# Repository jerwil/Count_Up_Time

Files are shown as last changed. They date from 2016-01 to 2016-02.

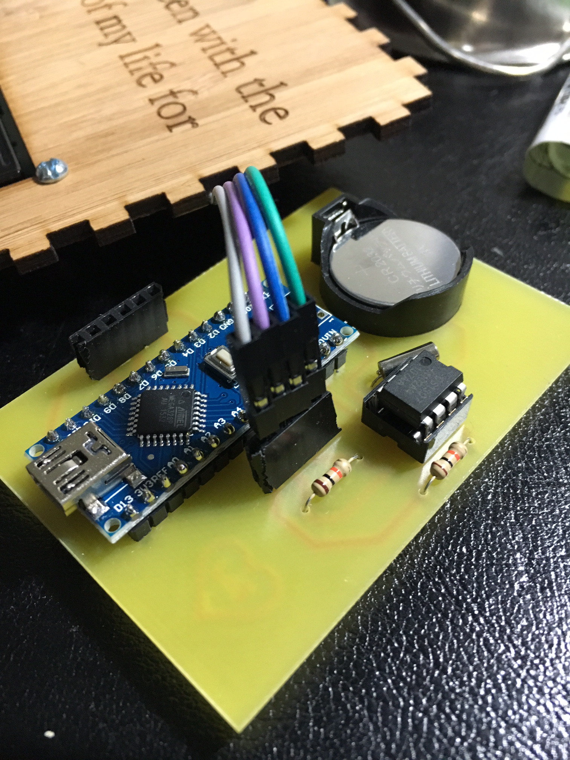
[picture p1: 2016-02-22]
Photos/IMG_2618.JPG

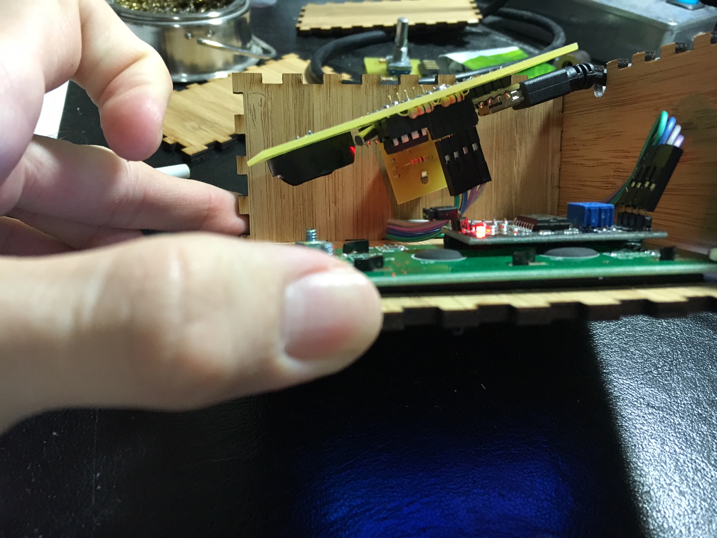
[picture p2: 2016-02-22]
Photos/IMG_2621.JPG

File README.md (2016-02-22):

# Count Up Box

This is a project I created as a Valentine's day gift to my girlfriend. It counts up the amount of time we have been together as a couple in various units.

![] (https://github.com/jerwil/Count_Up_Time/raw/master/Photos/Front.JPG "Front View")
![] (https://github.com/jerwil/Count_Up_Time/raw/master/Photos/Back.JPG "Back View")

## Features

* Displays amount of time since our first date in various units of time.
* Uses a rotary encoder to determine direction knob is turned.
* Backlight can be toggled using rotary encoder's built in momentary button.

## How to Use

* Press the button to turn on/off the backlight.
* Turn the knob to change the units being displayed or the current time and date.
* When displaying current time or date, hold down the button for 3 seconds to edit. Hold down again to switch between hours and minutes.

## Blog Post

Check out the associated blog post here: [Count up Box - A Valentine's Day Gift](http://www.jeremyadamwilson.com/count-up-box/)

## Demo Video

[Demo Video](https://youtu.be/PbRNsSK7r4M)

## Requirements

### Software

I used the LiquidCrystal_I2C library, which you can obtain here: [LiquidCrystal I2C](https://github.com/marcoschwartz/LiquidCrystal_I2C)

### Hardware

* Arduino Nano (or equivalent)
* DS1307 RTC (Real time clock)
* 32.768 kHz crystal oscillator
* 220Ω resistor
* 4 10kΩ resistors (2 for rotary encoder, 2 for RTC)
* 1602 LCD Screen with HD44780 controller
* IIC/I2C Serial Interface Adapter Module (To communicate to screen via I2C)
* Rotary encoder
* Battery holder
* Body/housing (lasercut design included in repository)

![] (https://github.com/jerwil/Count_Up_Time/raw/master/Photos/IMG_2618.JPG "Circuit board picture")
![] (https://github.com/jerwil/Count_Up_Time/raw/master/Photos/IMG_2620.JPG "View inside box")

### Schematics

![] (https://github.com/jerwil/Count_Up_Time/raw/master/Photos/Count%20Up%20Box%20Schematic%20Production_pcb.png "Circuit Board Layout")
![] (https://github.com/jerwil/Count_Up_Time/raw/master/Photos/Rotary%20Encoder%20Mini%20Board_pcb.png "Rotary Encoder Board")

See the included Fritzing diagram (.fzz file) for details.

### License

<br /><span xmlns:dct="http://purl.org/dc/terms/" property="dct:title">Count up box</span> by <a xmlns:cc="http://creativecommons.org/ns#" href="http://www.JeremyAdamWilson.com">Jeremy Wilson</a> is licensed under a <a rel="license" href="http://creativecommons.org/licenses/by-nc/4.0/">Creative Commons Attribution-NonCommercial 4.0 International License</a>.

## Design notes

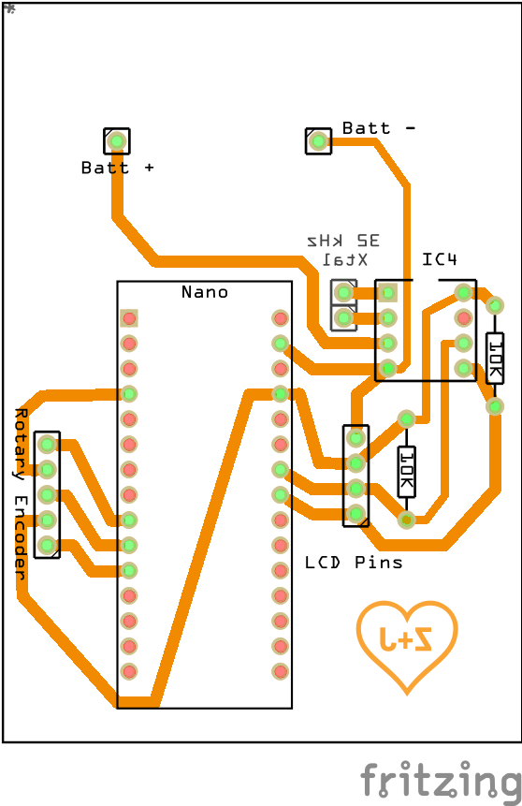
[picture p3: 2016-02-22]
Photos/Count Up Box Schematic Production_pcb.png

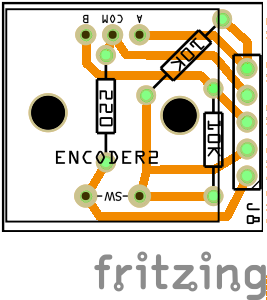
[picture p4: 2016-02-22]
Photos/Rotary Encoder Mini Board_pcb.png

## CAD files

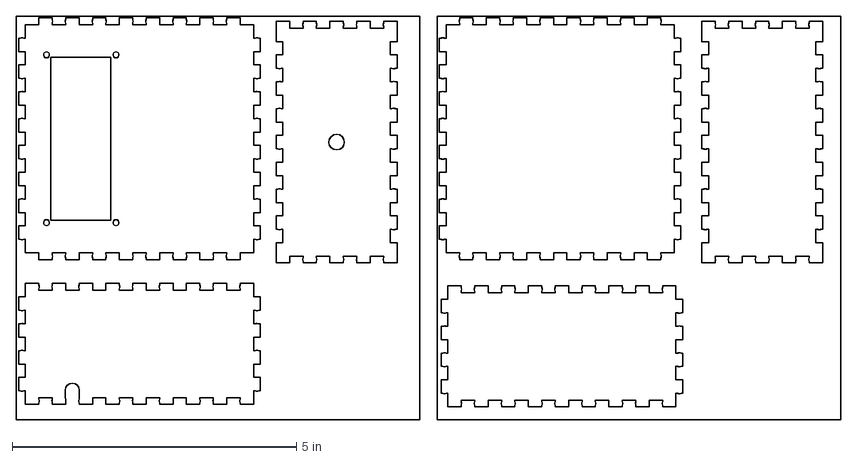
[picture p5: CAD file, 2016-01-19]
Laser Cutting Files/Time count up box 2 sheets.dxf
14.5 x 7.10 in

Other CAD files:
Laser Cutting Files/Time count up box 2 sheets.dwg

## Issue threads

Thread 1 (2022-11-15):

lcd blinking

Joscorb, 2022-11-15:
hello, when I tried this and uploaded the code, the lcd started blinking and changing display fastly and by it self. please any help?

jerwil, 2022-11-18:
Hi, I think it's cool that you're trying out my project! If you're having issues with the LCD, I would suggest that you isolate the problem by trying the example code from the LiquidCrystal_I2C library. If you find the same behavior using the example code, then I would suggest you check your wiring and power to make sure the physical setup is correct.

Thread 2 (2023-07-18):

"Set time" and "Set date" not working

BlindForLove, 2023-07-18:
Hi, it's been a while since the first version (7 years ago)

I hope you could help me with this problem.

When I upload the code everything works fine except 3 things:

1: the seconds counter does not update even in the rtc is working
2: if I move the rotatory encoder to the "The date" mode, after 2 seconds of not touching anything, the code goes automatically to "set date".
3: The same as 2 but with the time

Edit: I would be very pleased if I could get anyway to contact directly to you. tysm
Edit 2: It seems that problem 2 and 3 are caused by the rotary encoder switch, it seems like when it is not pressed, it acts like it is pressed and viceversa,  any solution to this?
Edit 3:Solved! If anyone has the same problem just change this line:

  **if (button_state == HIGH){**
   button_hi = true;
   timeout = 0;
  }
  else {button_hi = false;}

to this one:

  **if (button_state == LOW){**
   button_hi = true;
   timeout = 0;
  }
  else {button_hi = false;}

jerwil, 2023-07-19:
Thanks for taking the time to write up a solution when you figured this out! It could perhaps be the case that you are using a rotary encoder with a normally-closed button rather than a normally-open one. I would love to see the finished product when you're done!

Closed 2023-07-18.

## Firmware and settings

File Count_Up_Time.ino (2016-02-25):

// Date and time functions using a DS1307 RTC connected via I2C and Wire lib

// http://www.geeetech.com/wiki/index.php/Serial_I2C_1602_16%C3%972_Character_LCD_Module

// https://learn.adafruit.com/i2c-spi-lcd-backpack/connect-to-i2c

// https://github.com/marcoschwartz/LiquidCrystal_I2C The library used

// http://arduino.cc/playground/Main/I2cScanner


#include <RTClib.h>

/*
  Blink
  Turns on an LED on for one second, then off for one second, repeatedly.
 
  This example code is in the public domain.
 */

#include <Wire.h>
#include <LiquidCrystal_I2C.h>



LiquidCrystal_I2C lcd(0x27,16,2);  // set the LCD address to 0x27 for a 16 chars and 2 line display

RTC_DS1307 RTC;
 
// Hardware variables
const int pin_A = 6;  // pin 12
const int pin_B = 7;  // pin 11
const int ButtonPin = 8;

int MonthDayCounts[12] = {31,28,31,30,31,30,31,31,30,31,30,31}; // The number of days in each month


// Variables for the rotary encodier
unsigned char encoder_A;
unsigned char encoder_B;
unsigned char encoder_A_prev=0;
int clockwise = 0;
int counterclockwise = 0;

double mode = 0;
char* sub_mode = "hour set";

// Variables to keep track of last string printed to ensure screen is only changed when input changes
String LastString1;
String LastString2;


// Button press completion check variables
int button_state = 0;
int button_pushed = 0; // This is the indicator that the button was pushed and released
int button_counter = 0; // This is used to detect how long the button is held for
int button_press_initiate[1];     // storage for button press function
int button_press_completed[1];    // storage for button press function
int timeout = 0; // Time out for not pushing the button for a while
boolean button_hi = false;

// Boolean for the backlight LED status
bool LCDon = true;

//Boolean for cursor status
bool cursoron = false;

// Variables for displaying time
int hour_int = 0;
int minute_int = 0;
int second_int = 0;
int month_int = 0;
int day_int = 0;
int year_int = 0;
int digit_array[8] = {0,0,0,0,0,0,0,0};
int time_array[3] = {0,0,0};

// Tick timer veriables
double second_timer[1] = {0}; // This is used to keep track of the timer used to tick for each second
int old_second = 0; //This is used for the tick mechanism
int now_second = 0;
unsigned long currentTime;
int cursor_blink = 0;

// the setup routine runs once when you press reset:
void setup() {
  Serial.begin(57600); 
#ifdef AVR
  Wire.begin();
#else
  Wire1.begin(); // Shield I2C pins connect to alt I2C bus on Arduino Due
#endif
  RTC.begin();

    if (! RTC.isrunning()) {
    Serial.println("RTC is NOT running!");
    // following line sets the RTC to the date & time this sketch was compiled
    //RTC.adjust(DateTime(F(__DATE__), F(__TIME__)));
    // This line sets the RTC with an explicit date & time, for example to set
    // January 21, 2014 at 3am you would call:
    //RTC.adjust(DateTime(2014, 1, 21, 3, 0, 0));
  }

//RTC.adjust(DateTime(F(__DATE__), F(__TIME__)));
               
  pinMode(pin_A, INPUT);
  pinMode(pin_B, INPUT);
  pinMode(ButtonPin, INPUT);

  lcd.init();
  lcd.backlight();    
}


// the loop routine runs over and over again forever:
void loop() {
  clockwise = 0;
  encoder_A = digitalRead(pin_A);    // Read encoder pins
  encoder_B = digitalRead(pin_B);   
  if((!encoder_A) && (encoder_A_prev)){
    // A has gone from high to low 
    if(encoder_B) {
      Serial.println("Clockwise");
      if (mode != 5.5 && mode != 6.5){mode += 1;}
      // B is high so clockwise
      clockwise = 1;
      timeout = 0;            
    }   
    else {
      Serial.println("Counter Clockwise");
      if (mode != 5.5 && mode != 6.5){mode -= 1;} 
      // B is low so counter-clockwise      
      clockwise = -1;
      timeout = 0;              
    }   
  }
  encoder_A_prev = encoder_A;
  
  button_state = digitalRead(ButtonPin);
  button_pushed = button_press (button_state, button_press_initiate, button_press_completed);


  if (button_state == HIGH){
   button_hi = true;
   timeout = 0; 
  }
  else {button_hi = false;}


// Toggle the backlight with a button press
  if (button_pushed == 1){
    if (LCDon){LCDon = false;}
    else {LCDon = true;}
  }


  if (mode < 0){mode = 6;}
  else if (mode >= 7){mode = 0;}

DateTime now = RTC.now();
DateTime aniv = (1422126000); // The unixtime format of our anniversary date

  month_int = now.month();
  day_int = now.day();
  year_int = now.year();
  hour_int = now.hour();
  minute_int = now.minute();
  second_int = now.second();


  if (now.year() % 4 == 0){MonthDayCounts[1] = 29;}
  else {MonthDayCounts[1] = 28;}

  long SecondsSince = now.unixtime() - aniv.unixtime();
  long MinutesSince = SecondsSince/60;
  long HoursSince = MinutesSince/60;
  long DaysSince = HoursSince/24;
  long DaysOfMonthSince = MonthDayCounts[now.month()-2]- aniv.day() + now.day();
  long MonthsSince = (now.year()-aniv.year())*12+(now.month()-aniv.month()-1);
  if (now.day() >= aniv.day()){
  MonthsSince += 1;
  DaysOfMonthSince = now.day()- aniv.day();
  }
  
    
    
  if (mode == 0){
      printstring1(String(SecondsSince));
      printstring2("Seconds");
  }
  else if (mode == 1){
      printstring1(String(MinutesSince));
      printstring2("Minutes");
  }
  else if (mode == 2){
      printstring1(String(HoursSince));
      printstring2("Hours");
  }
  else if (mode == 3){
      printstring1(String(DaysSince));
      printstring2("Days");
  }
  else if (mode == 4){
      printstring1(String(MonthsSince) + " Months");
      printstring2(String(DaysOfMonthSince) + " Days");
  }
  else if (mode == 5){
    if (tick(1000, second_timer) == 1){  
      if (button_hi == true){ 
        if (button_counter >= 2) { // This code checks to see if the button has been held down long enough to set time
        mode = 5.5;
        button_counter = 0;
        button_pushed = 0;
        timeout = 0;
        sub_mode = "hour set"; 
        }
      button_counter += 1;
      }
      else {
         button_counter = 0; 
      }
    }
 
    time_to_array(hour_int, minute_int, second_int);
    String stringOne =  String(digit_array[0]) + String(digit_array[1]) + ':' + String(digit_array[2]) + String(digit_array[3]) + ':' + String(digit_array[4] + String(digit_array[5]));
    printstring1(stringOne);
    printstring2("The time");
  }
  else if (mode == 5.5){ 
    if (tick(1000, second_timer) == 1){  
      if (button_hi == true){ 
      button_counter += 1;
      }
      else {
         button_counter = 0; 
         timeout += 1;
      }
      if (cursor_blink == 0){
        cursor_blink = 1;
        lcd.cursor();
      }
      else if (cursor_blink == 1){
        cursor_blink = 0;
        lcd.noCursor();
      }
      }
    if (timeout >= 60){
      mode = 5;
      timeout = 0;
      lcd.noCursor();
    }
    if (sub_mode == "hour set"){
    lcd.setCursor(1,0);
    if (clockwise == 1 && time_array[0] < 24){
      time_array[0] += 1;
      }
    else if (clockwise == -1 && time_array[0] > 0){
      time_array[0] -= 1;
    }
    if (button_counter >= 2) { // This code checks to see if the button has been held down long enough to change to setting minutes
      sub_mode = "minute set";
      button_counter = 0;
      button_pushed = 0;
      timeout = 0;
      button_press_initiate[0] = 0; 
    }    
    }
    else if (sub_mode == "minute set"){
    lcd.setCursor(4,0);
    if (clockwise == 1 && time_array[1] < 59){
      time_array[1] += 1;
      }
    else if (clockwise == -1 && time_array[1] > 0){
      time_array[1] -= 1;
    }
    if (button_counter >= 2) {
      mode = 5;
      sub_mode = "hour set";
      button_counter = 0;
      button_pushed = 0;
      timeout = 0;
      button_press_initiate[0] = 0;
      lcd.noCursor();
      RTC.adjust(DateTime(now.year(), now.month(), now.day(), time_array[0], time_array[1], now.second())); 
    }    
    }
    else{
    mode = 5;
    sub_mode = "hour set";
    }
 
    time_to_array(time_array[0], time_array[1], time_array[2]);
    
    String stringOne =  String(digit_array[0]) + String(digit_array[1]) + ':' + String(digit_array[2]) + String(digit_array[3]) + ':' + String(digit_array[4] + String(digit_array[5]));
    printstring1(stringOne);
    printstring2("Time Set");
    LCDon = true;
  }
  else if (mode == 6){
    if (tick(1000, second_timer) == 1){  
      if (button_hi == true){ // This code checks to see if the button has been held down long enough to set date
        if (button_counter >= 3) {
        mode = 6.5;
        button_counter = 0;
        button_pushed = 0;
        timeout = 0;
        sub_mode = "month set";
        date_to_array(now.month(), now.day(), now.year()); 
        }
      button_counter += 1;
      }
      else {
         button_counter = 0; 
      }
    }
    String stringOne =  String(month_int) + '/' + String(day_int) + '/' + String(year_int);
    printstring1(stringOne);
    printstring2("The Date");
  }
  else if (mode == 6.5){
    if (tick(1000, second_timer) == 1){  
      if (button_hi == true){ // This code checks to see if the button has been held down long enough to set date
        if (button_counter >= 3) {
        mode = 6;
        button_counter = 0;
        button_pushed = 0;
        timeout = 0;
        button_press_initiate[0] = 0; 
        }
      button_counter += 1;
      }
      else {
         button_counter = 0; 
         timeout += 1;
      }
      if (cursor_blink == 0){
        cursor_blink = 1;
        lcd.cursor();
      }
      else if (cursor_blink == 1){
        cursor_blink = 0;
        lcd.noCursor();
      }      
    }
    if (timeout >= 60){
      mode = 6;
      timeout = 0;
    }
    if (sub_mode == "month set"){
    lcd.setCursor(1,0);
    if (clockwise == 1 && time_array[0] < 12){
      time_array[0] += 1;
      }
    else if (clockwise == -1 && time_array[0] > 1){
      time_array[0] -= 1;
    }
    if (button_counter >= 2) {
      sub_mode = "day set";
      button_counter = 0;
      button_pushed = 0;
      timeout = 0;
      button_press_initiate[0] = 0; 
    }    
    }
    else if (sub_mode == "day set"){
      lcd.setCursor(4,0);
      if (clockwise == 1 && time_array[1] < MonthDayCounts[time_array[0]-1]){ // Don't allow a day not within current month. This is why month is set first!
        time_array[1] += 1;
        }
      else if (clockwise == -1 && time_array[1] > 1){
        time_array[1] -= 1;
      }
      if (button_counter >= 2) {
        sub_mode = "year set";
        button_counter = 0;
        button_pushed = 0;
        timeout = 0;
        button_press_initiate[0] = 0; 
      }    
    }
    else if (sub_mode == "year set"){
    lcd.setCursor(9,0);
    if (clockwise == 1){
      time_array[2] += 1;
      }
    else if (clockwise == -1 && time_array[2] > 1971){
      time_array[2] -= 1;
    }
    if (button_counter >= 2) {
      mode = 6;
      sub_mode = "hour set";
      button_counter = 0;
      button_pushed = 0;
      timeout = 0;
      button_press_initiate[0] = 0;
      lcd.noCursor();
      RTC.adjust(DateTime(time_array[2], time_array[0], time_array[1], now.hour(), now.minute(), now.second())); 
    }    
    }
    date_to_array(time_array[0], time_array[1], time_array[2]);
    printstring1(String(digit_array[0]) + String(digit_array[1]) + '/' + String(digit_array[2]) + String(digit_array[3]) + '/' + String(time_array[2]));
    printstring2("Set Date");
    LCDon = true;
  }  
  else {
    printstring1("Error!");
    printstring2("");
  } 

if (LCDon){lcd.backlight();}
else {lcd.noBacklight();}
    
}


void printstring1(String stringtoprint) {
  if (LastString1 != stringtoprint){
  String stringgoingtoprint = stringtoprint;
  // Add a while loop to add spaces to the end
  while(stringgoingtoprint.length() < 16){stringgoingtoprint += " ";}
  int stringlength = stringgoingtoprint.length();
  char StringChar[stringlength + 1]; 
  stringgoingtoprint.toCharArray(StringChar, stringlength + 1);
  for (int i = 0; i < stringlength; i++){
  lcd.setCursor(i, 0);
  lcd.print(StringChar[i]);
  }
  }
  LastString1 = stringtoprint;
}

void printstring2(String stringtoprint) {
  if (LastString2 != stringtoprint){
  String stringgoingtoprint = stringtoprint;
  while(stringgoingtoprint.length() < 16){stringgoingtoprint += " ";}
  int stringlength = stringgoingtoprint.length();
  char StringChar[stringlength + 1]; 
 stringgoingtoprint.toCharArray(StringChar, stringlength + 1);
  for (int i = 0; i < stringlength; i++){
  lcd.setCursor(i, 1);
  lcd.print(StringChar[i]);
  }
  }
  LastString2 = stringtoprint;
}

int button_press (int button_indicator, int button_press_initiated[1], int button_press_complete[1]){
  if (button_indicator == 0 && button_press_initiated[0] == 1) {
  button_press_complete[0] = 1;
  button_press_initiated[0] = 0;
  }
  else if (button_indicator == 1){
  button_press_initiated[0] = 1;
  button_press_complete[0] = 0;
  }
  else {button_press_complete[0] = 0;}
return button_press_complete[0];
}

void time_to_array(int hour_int, int minute_int, int second_int){
   time_array[0] = hour_int;
   time_array[1] = minute_int;
   time_array[2] = second_int;
   
     if (hour_int < 10 && hour_int > 0){
    digit_array[0] = 0; // 10 will be the designation for not displaying anything
    digit_array[1] = hour_int;
  }
  else {
    digit_array[0] = hour_int/10;
    digit_array[1] = hour_int%10;
  }
  if (minute_int < 10){
  digit_array[2] = 0; // 10 will be the designation for not displaying anything
  digit_array[3] = minute_int;
  }
  else {
    digit_array[2] = minute_int/10;
    digit_array[3] = minute_int%10;
  }
  if (second_int < 10){
  digit_array[4] = 0; // 10 will be the designation for not displaying anything
  digit_array[5] = second_int;
  }
  else {
    digit_array[4] = second_int/10;
    digit_array[5] = second_int%10;
  }
}

void date_to_array(int month_int, int day_int, int year_int){
   time_array[0] = month_int;
   time_array[1] = day_int;
   time_array[2] = year_int;
   
     if (month_int < 10 && month_int > 0){
    digit_array[0] = 0; // 10 will be the designation for not displaying anything
    digit_array[1] = month_int;
  }
  else {
    digit_array[0] = month_int/10;
    digit_array[1] = month_int%10;
  }
  if (day_int < 10){
  digit_array[2] = 0; // 10 will be the designation for not displaying anything
  digit_array[3] = day_int;
  }
  else {
    digit_array[2] = day_int/10;
    digit_array[3] = day_int%10;
  }
}

int tick(int delay, double timekeeper[1]){
currentTime = millis();
if(currentTime >= (timekeeper[0] + delay)){
  timekeeper[0] = currentTime;
  return 1;
  }
else {return 0;}
}

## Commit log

2016-01-19 Initial commit. Screen displays current time
    [Count Up Box Schematic.fzz, Time count up box 2 sheets.dwg, Time count up box 2 sheets.dxf]
2016-01-19 Added main components onto bread board
    Need to arrange PCB and determine how rotary encoder will attach.
    Thinking of making small interface board that plugs into main board at
    90 degree angle
    [Count Up Box Schematic.fzz]
2016-01-26 Made sub-board for rotary encoder
    [Count Up Box Schematic.fzz, Rotary Encoder Mini Board.fzz]
2016-01-27 Produced circuit board, basic time calculations working
    Rotary encoder not yet working. Need to troubleshoot
    [Count Up Box Features.xlsx, Count Up Box Schematic Production.fzz]
2016-02-10 Started from scratch on rotary encoder code
    Basic functions are working. String is only printed when it changes, and
    screen is cleared with each rotary encoder step. Need to replace this
    with spaces at the end of strings to clear extra space instead. Still
    only integers. Screen turns on/off with button
    [Count_Up_Time.ino]
2016-02-11 Made mode for months + days, got time to sync with PC on compile
    [Count Up Box Features.xlsx]
2016-02-13 Went back to original filename, time now ok
    Time displays with 0s, and added state to show date. Added transition to
    time and date set modes, but need to implement modes
    [Count Up Box Schematic Production.fzz, Rotary Encoder Mini Board.fzz]
2016-02-22 Created readme, organized files, added photos
    [Count Up Box Features.xlsx, Count Up Box Schematic Production.fzz, Count Up Box Schematic.fzz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]
2016-02-25 Made cursor flash when adjusting time or date
    Also restricted day entry based on month, and fixed bug that would allow
    months or days of value 0.
    [Count_Up_Time.ino]
